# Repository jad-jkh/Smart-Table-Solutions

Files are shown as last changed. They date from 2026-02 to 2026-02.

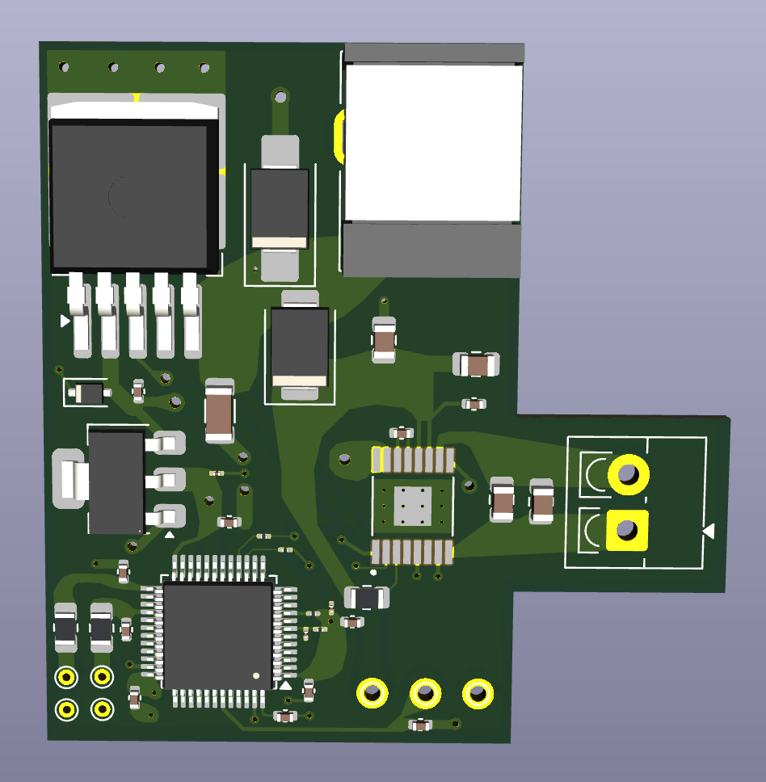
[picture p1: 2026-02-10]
screenshots/pcb_3d.png

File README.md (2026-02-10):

# Smart-Table-Solutions

Sample files from Jad Haddad's Smart Table Solutions including: KiCad PCB files (schematic, layout, and 3D view) and screenshots, along with embedded C code for motor control.

## Overview
Smart Table Solutions provides an automated height-adjustable table control system using an STM32F103C8T6 (Blue Pill) microcontroller and DRV8876 motor driver. The system allows users to adjust table height via simple button controls.

## Hardware Components
- **Microcontroller:** STM32F103C8T6 (Blue Pill)
- **Motor Driver:** DRV8876
- **Buttons:** 2x momentary push buttons (Up/Down control)
- **LED:** Status indicator (reserved for future features)

## Pin Configuration
| Component | Pin | Description |
|---|---|---|
| Button Down  | PB12 | Active LOW with internal pull-up |
| Button Up | PB15 | Active LOW with internal pull-up |
| Motor Enable | (IN1/EN) | PA6 | Enable signal to DRV8876 |
| Motor Phase  | (IN2/PH) | PA5 | Phase/direction control to DRV8876  |
| LED Reserve  | PB7 | Reserved for future add-on features |

## Functionality
- **Hold DOWN button (PB12):** Motor drives table downward
- **Hold UP button (PB15):** Motor drives table upward
- **Hold BOTH buttons:** Motor stops (safety feature)
- **Release buttons:** Motor stops

## Software
The embedded firmware is written in C using the Arduino framework with STM32duino support.

### Features
- Simple hold-to-run button logic
- Safety stop when both buttons pressed simultaneously
- 10ms software debouncing
- Reserved LED pin for custom add on

### Code Structure
- `motorControl.ino` - Main control logic for motor operations

## Setup Instructions

### Hardware Setup
1. Connect ST-Link programmer to Blue Pill SWD pins (SWDIO, SWCLK, GND, 3.3V)
2. Solder buttons to PB12 and PB15 with pull-up configuration and LED + controller if applicable
3. Solder DRV8876 motor driver IN1 to PA6, IN2 to PA5
4. Plug jack into female connector

### Software Setup
1. Install [Arduino IDE](https://www.arduino.cc/en/software)
2. Add STM32 board support:
   - Go to **Settings → Additional boards manager URLs**
   - Add: `https://github.com/stm32duino/BoardManagerFiles/raw/main/package_stmicroelectronics_index.json`
3. Install STM32 boards:
   - **Tools → Board → Boards Manager**
   - Search and install **"STM32 MCU based boards"**
4. Select board:
   - **Tools → Board → STM32 boards → Generic STM32F1 series**
   - **Tools → Board part number → BluePill F103C8**
   - **Tools → Upload method → STLink**
5. Open `motorControl.ino` and upload to Blue Pill

## Repository Contents
- `/pcb` - KiCad PCB design files
  - Schematic files
  - PCB layout
  - 3D view renders
- `/firmware` - Embedded C code
  - `motorControl.ino` - Motor control firmware
- `/screenshots` - Project documentation images

## Author
Jad Haddad

## Contact
jadkh6@gmail.com

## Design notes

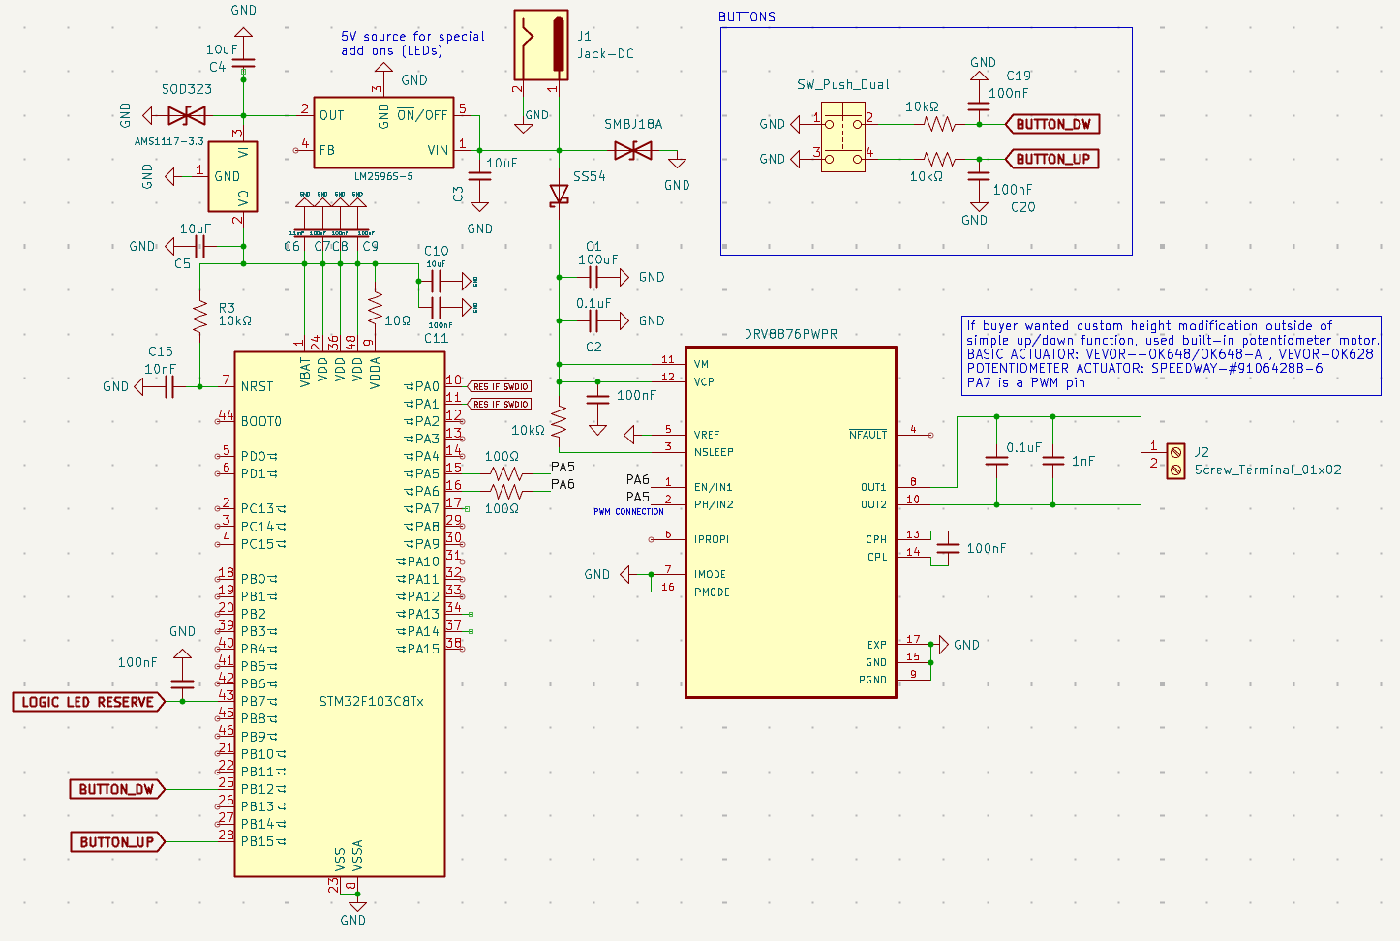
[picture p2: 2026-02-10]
screenshots/pcb_schematic.png

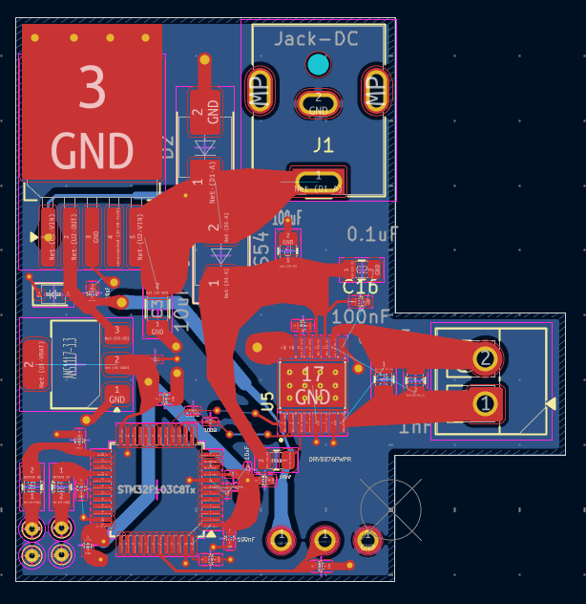
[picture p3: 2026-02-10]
screenshots/pcb_footprint.png

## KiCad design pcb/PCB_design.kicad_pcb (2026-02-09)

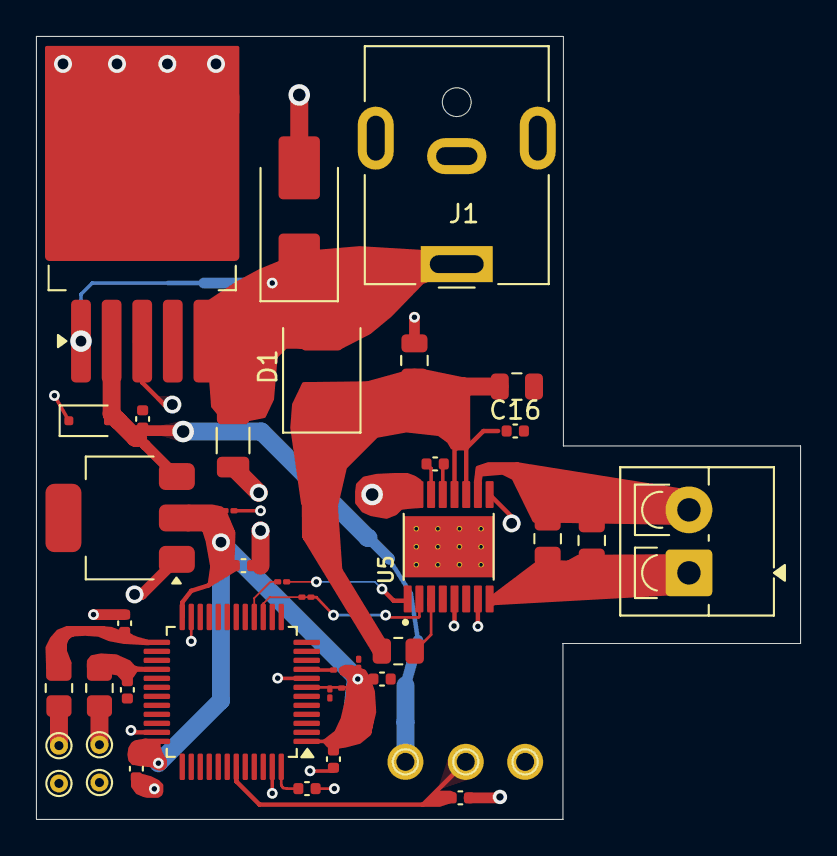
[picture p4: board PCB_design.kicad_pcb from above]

Board: 2 copper layers, 42.5 x 43.5 mm, 34 parts (0 on the bottom side), 18 nets.

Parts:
C1: 100uF; C_0805_2012Metric
C2, C12: 0.1uF; C_0805_2012Metric
C3: 10uF; C_1206_3216Metric
C4: 10uF; C_0402_1005Metric
C5, C10: 10uF; C_01005_0402Metric
C6: 0.1mF; C_0402_1005Metric
C7, C8, C9, C11, C14, C16, C19, C20, C20#2: 100nF; C_0402_1005Metric
C13: 1nF; C_0805_2012Metric
C15: 10nF; C_01005_0402Metric
D1: SS54; D_SMB
D2: SMBJ18A; D_SMB_Handsoldering
D3: SOD323; D_SOD-323F
J1: Jack-DC; BarrelJack_CUI_PJ-063AH_Horizontal
R1: 10kΩ; R_0805_2012Metric
R2: 10Ω; R_01005_0402Metric
R3: 10kΩ; R_01005_0402Metric
R4, R5: 100Ω; R_01005_0402Metric
R6, R7: 10kΩ; R_0805_2012Metric_Pad1.20x1.40mm_HandSolder
U1: STM32F103C8Tx; LQFP-48_7x7mm_P0.5mm
U2: LM2596S-5; TO-263-5_TabPin3
U3: AMS1117-3.3; SOT-223-3_TabPin2
U5: DRV8876PWPR; IC_DRV8876PWPR

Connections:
BUTTON_DW: C19.2, R6.2, U1.25 (PB12)
BUTTON_UP: C20#2.1, R7.1, U1.28 (PB15)
GND: C1.2, C2.2, C3.1, C4.2, C5.2, C6.1, C7.1, C8.1, C9.1, C10.1, C11.1, C15.1, C16.2, C19.1, C20.1, C20#2.2, D2.2 (A2), D3.1 (A1), J1.2, U1.8 (VSSA), U1.23 (VSS), U1.35 (VSS), U1.47 (VSS), U2.3 (GND), U3.1 (GND), U5.5 (VREF), U5.7 (IMODE), U5.15 (GND), U5.16 (PMODE), U5.17 (EXP)
unnamed: D1.2 (A), D2.1 (A1), J1.1
unnamed: C1.1, C2.1, C16.1, D1.1 (K), R1.2, U5.11 (VM), U5.12 (VCP)
unnamed: C12.1, U5.8 (OUT1)
unnamed: C13.2, U5.10 (OUT2)
unnamed: C15.2, R3.2, U1.7 (NRST)
unnamed: R5.1, R5.2, U1.15 (PA5), U5.2 (PH/IN2)
unnamed: R4.1, R4.2, U1.16 (PA6), U5.1 (EN/IN1)
unnamed: C5.1, C6.2, C7.2, C8.2, C9.2, C10.2, C11.2, R2.1, R3.1, U1.1 (VBAT), U1.24 (VDD), U1.36 (VDD), U1.48 (VDD), U3.2 (VO)
unnamed: R2.2, U1.9 (VDDA)
unnamed: C4.1, D3.2 (A2), U2.2 (OUT)
unnamed: C3.2, U2.1 (VIN), U2.5 (~ON/OFF)
unnamed: C14.1, U5.13 (CPH)
unnamed: C14.2, U5.14 (CPL)
unnamed: R1.1, U5.3 (NSLEEP)
RES IF SWDIO: U1.10 (PA0), U1.11 (PA1)

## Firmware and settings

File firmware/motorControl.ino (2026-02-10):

#define DOWN_BTN PB12
#define UP_BTN PB15
#define ENABLE PA6  // EN
#define MOTOR_CONTROL PA5  // PH
#define LED_RESERVE PB7

void setup() {
  // BUTTON PIN CONFIGURATION
  pinMode(DOWN_BTN, INPUT_PULLUP);
  pinMode(UP_BTN, INPUT_PULLUP);
  
  // MOTOR DRIVER PIN OUTPUT
  pinMode(ENABLE, OUTPUT);
  pinMode(MOTOR_CONTROL, OUTPUT);
  
  // RESERVED PIN, THIS TABLE DID NOT USE
  pinMode(LED_RESERVE, OUTPUT);
  
  // MOTOR INITIALIZED STOPPED
  digitalWrite(ENABLE, LOW);
  digitalWrite(MOTOR_CONTROL, LOW);
}

void loop() {

  if (digitalRead(DOWN_BTN) == LOW && digitalRead(UP_BTN) == LOW) {
  // BOTH PRESSED, STOP
  digitalWrite(ENABLE, LOW);
  digitalWrite(MOTOR_CONTROL, LOW);
  }

  // CHECK DOWN BUTTON (active low)
  else if (digitalRead(DOWN_BTN) == LOW) {
    digitalWrite(ENABLE, HIGH);
    digitalWrite(MOTOR_CONTROL, LOW);   // PH = LOW
  }
  // CHECK UP BUTTON (pull high)
  else if (digitalRead(UP_BTN) == LOW) {
    digitalWrite(ENABLE, HIGH);
    digitalWrite(MOTOR_CONTROL, HIGH);  // PH = HIGH
  }
  // No button pressed - Stop
  else {
    digitalWrite(ENABLE, LOW);   // EN = LOW
    digitalWrite(MOTOR_CONTROL, LOW);   // PH = LOW
  }
  
  delay(10);  // DEBOUNCE 10MS
}
